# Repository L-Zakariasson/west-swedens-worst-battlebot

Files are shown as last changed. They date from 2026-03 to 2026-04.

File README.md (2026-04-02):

This is a school project for my integrated systems course.
Using C and the atmega 328p processor I am creating a very shitty battlebot.

The hardware includes a HC-06 bluetooth module, a 5 to 3,3 V logic converter, and the Motron M3T453 i2c motor controller.
It takes commands from a ps5 controller using a computer running a python script to send commands over BT serial and the bot uses  that to control two motors to provide "Tank" steering and one motor for the weapon.

The chassi is built using Lego.

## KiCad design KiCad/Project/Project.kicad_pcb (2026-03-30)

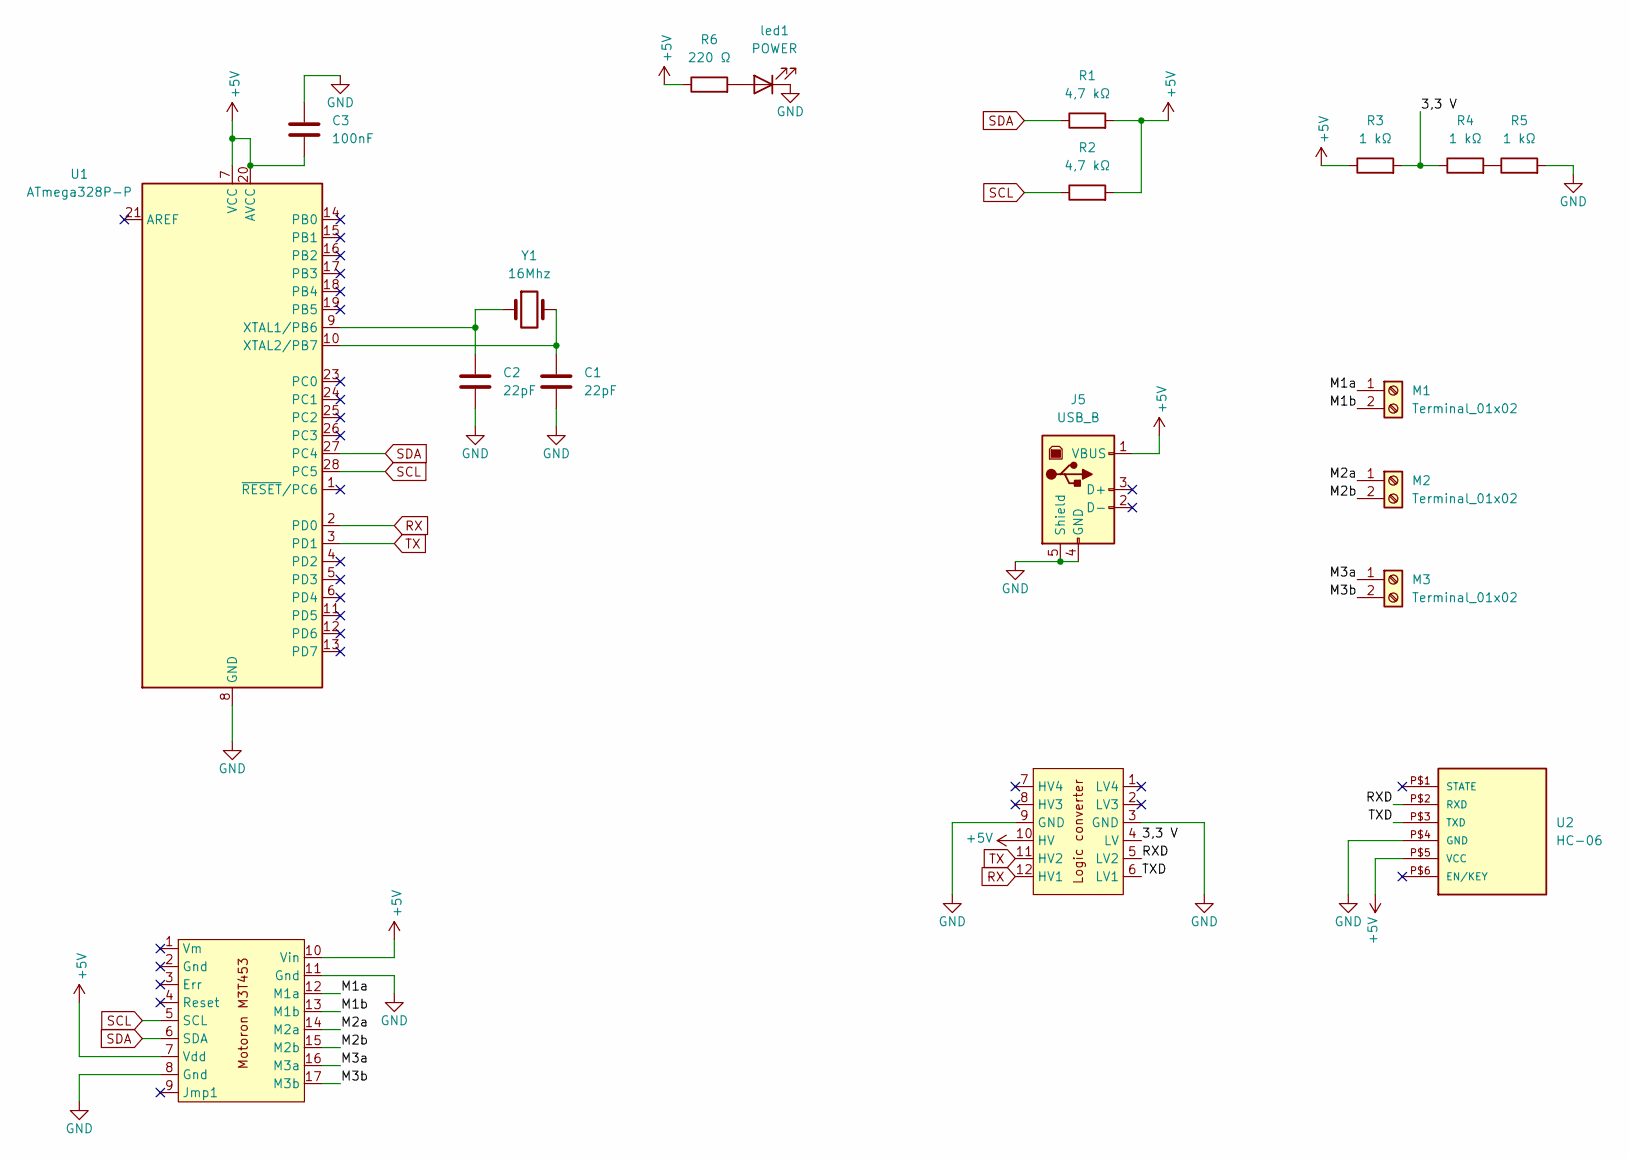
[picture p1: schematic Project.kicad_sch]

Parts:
C1, C2: 22pF; C_Disc_D5.0mm_W2.5mm_P2.50mm
C3: 100nF; C_Rect_L7.2mm_W2.5mm_P5.00mm_FKS2_FKP2_MKS2_MKP2
J5: USB_B; USB_B_Lumberg_2411_02_Horizontal
M1, M2, M3: Terminal_01x02; TerminalBlock_MetzConnect_Type094_RT03502HBLU_1x02_P5.00mm_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
R1, R2: 4,7 kΩ; R_Axial_DIN0207_L6.3mm_D2.5mm_P7.62mm_Horizontal
R3, R4, R5: 1 kΩ; R_Axial_DIN0207_L6.3mm_D2.5mm_P7.62mm_Horizontal
R6: 220 Ω; R_Axial_DIN0207_L6.3mm_D2.5mm_P7.62mm_Horizontal
U1: ATmega328P-P; ZIF 28pin den hos elektrokit, maybe
U2: HC-06
U3: motron m3t453
U5: logic converter
Y1: 16Mhz; Crystal_HC49-U_Vertical
led1: POWER; LED_D5.0mm

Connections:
+5V: C3.2, J5.1 (VBUS), R1.2, R2.2, R3.1, R6.1, U1.7 (VCC), U1.20 (AVCC), U2.P$5 (VCC), U3.7 (Vdd), U3.10 (Vin), U5.10 (HV)
/3,3 V: R3.2, R4.1, U5.4 (LV)
/M1a: M1.1, U3.12 (M1a)
/M1b: M1.2, U3.13 (M1b)
/M2a: M2.1, U3.14 (M2a)
/M2b: M2.2, U3.15 (M2b)
/M3a: M3.1, U3.16 (M3a)
/M3b: M3.2, U3.17 (M3b)
/RXD: U2.P$2 (RXD), U5.5 (LV2)
/TXD: U2.P$3 (TXD), U5.6 (LV1)
GND: C1.2, C2.2, C3.1, J5.4 (GND), J5.5 (Shield), R5.2, U1.8 (GND), U1.22 (GND), U2.P$4 (GND), U3.8 (Gnd), U3.11 (Gnd), U5.3 (GND), U5.9 (GND), led1.1 (K)
unnamed: R4.2, R5.1
unnamed: C2.1, U1.9 (XTAL1/PB6), Y1.1
unnamed: C1.1, U1.10 (XTAL2/PB7), Y1.2
unnamed: R6.2, led1.2 (A)
RX: U1.2 (PD0), U5.12 (HV1)
SCL: R2.1, U1.28 (PC5), U3.5 (SCL)
SDA: R1.1, U1.27 (PC4), U3.6 (SDA)
TX: U1.3 (PD1), U5.11 (HV2)

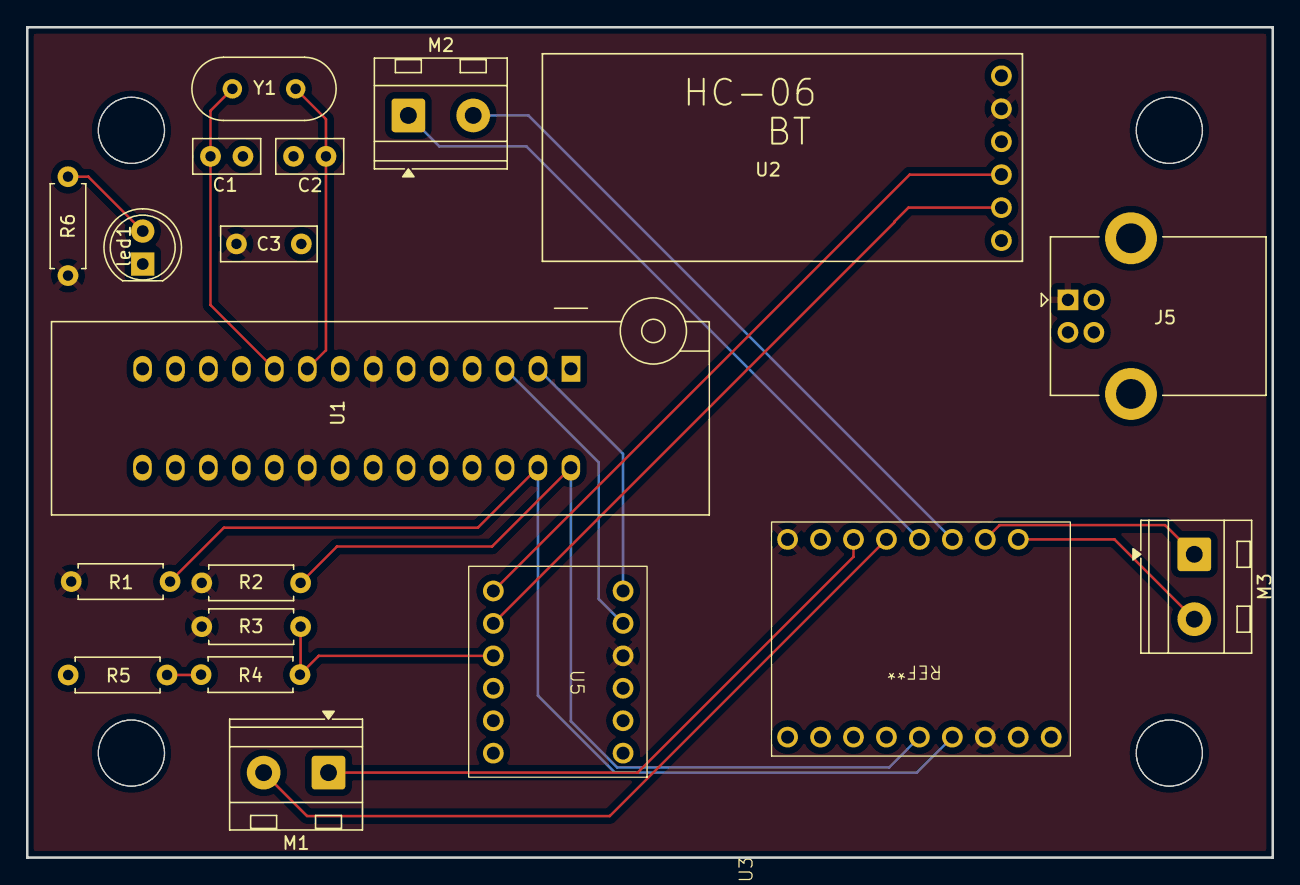
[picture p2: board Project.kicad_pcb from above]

Board: 2 copper layers, 96.0 x 64.0 mm, 19 parts (0 on the bottom side), 19 nets.

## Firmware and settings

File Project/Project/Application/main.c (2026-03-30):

/*
 * Project.c
 *
 * Created: 2026-02-10 15:39:32
 * Author : ludvig
 */ 

 
#include "include.h"


volatile uint8_t rx_input = 0;
volatile uint8_t uart_command[3] = {0,0,0};
volatile uint8_t uart_command_counter = 0;


ISR (USART_RX_vect){ /*interrupt to get serial data*/
    rx_input = UDR0;
    if (uart_command_counter < 3) {
        if (61==rx_input || 62==rx_input) {
            uart_command[0] = rx_input;
        } else if (0==(rx_input>>6) || 1==(rx_input>>6)) {
            uart_command[1] = rx_input;
        } else if (2==(rx_input>>6) || 3==(rx_input>>6)) {
            uart_command[2] = rx_input;
        }
        
        uart_command_counter++;  
    }  
}
    

int main(void)
{
     
    i2c_init(); /*setup i2c communication in atmega*/
    motron_init(); /*setup motor controller with default settings*/
    uart_init(104); /*setup uart with 9600 baud*/
    sei();
    while (1) {   
        if (uart_command_counter >= 3) {
        
            if (61 == uart_command[0]) {
                set_motor_3_speed(800);
            } else if (62 == uart_command[0]) {
                set_motor_3_speed(0);
            }
            
            if (uart_command[1]>>6 == 1) {
                uart_command[1] = uart_command[1] & 0b00111111;
                set_motor_1_speed(uart_command[1]*13);                
            } else if (uart_command[1]>>6 == 0) {
                uart_command[1] = uart_command[1] & 0b00111111;
                set_motor_1_speed(uart_command[1]*(-13));                    
            }
            
            if (uart_command[2]>>6 == 3) {
                uart_command[2] = uart_command[2] & 0b00111111;
                set_motor_2_speed(uart_command[2]*13);                 
            } else if (uart_command[2]>>6 == 2) {
                 uart_command[2] = uart_command[2] & 0b00111111;
                 set_motor_2_speed(uart_command[2]*(-13));                  
            }
                        
            uart_command_counter = 0;
        }
              
    }
}

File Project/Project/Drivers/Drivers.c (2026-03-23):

/*
 * Drivers.c
 *
 * Created: 2026-03-12 10:17:34
 *  Author: ludvig
 */ 

#include "include.h"

void i2c_init (void){
    TWCR = 0x00;
    TWBR = 0x08;            /*clock speed, under 400kHz*/
    TWCR = 0x04;
}

void i2c_start(void){
    TWCR = (1 << TWINT | (1<< TWSTA) | (1 << TWEN));
    while((TWCR & (1<<TWINT)) == 0);
}

void i2c_write (uint8_t data){
    TWDR = data;
    TWCR = (1<<TWINT) | (1<<TWEN);
    while ((TWCR & (1<<TWINT)) == 0);
}

void i2c_stop (void){
    TWCR = (1<<TWINT) | (1<<TWEN) | (1<<TWSTO);
}

void uart_init(uint8_t baud){
    UCSR0B = (1<<TXEN0) | (1<<RXEN0) | (1<<RXCIE0);
    UCSR0C = (1<<UCSZ01) | (1<<UCSZ00);
    UBRR0L = baud;
}

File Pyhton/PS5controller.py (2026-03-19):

# Example file showing a basic pygame "game loop"
import pygame
import serial

# pygame setup
pygame.init()

screen = pygame.display.set_mode((720, 360))
clock = pygame.time.Clock()
running = True

controller = pygame.joystick.Joystick(0)
serialPort = serial.Serial(
    port="COM12", baudrate=9600, bytesize=8, timeout=2, stopbits=serial.STOPBITS_ONE
)

while running:

    for event in pygame.event.get():
        if event.type == pygame.QUIT:
            running = False
	

    if controller.get_button(10) == 1:
        weapon = bytes([61])

        print(weapon)
        serialPort.write(weapon)
    else: 
        weapon = bytes([62])

        print(weapon)
        serialPort.write(weapon)

    if controller.get_axis(1) > 0:
        motorspped_l_down = bytes([abs(int(round(controller.get_axis(1)*60)))+0])
        
        print("L stick down ",motorspped_l_down)
        serialPort.write(motorspped_l_down)

    if controller.get_axis(1) < 0:
        motorspped_l_up = bytes([abs(int(round(controller.get_axis(1)*60)))+64])

        print("L stick up ",motorspped_l_up)
        serialPort.write(motorspped_l_up)       

    if controller.get_axis(3) > 0:
        motorspped_r_down = bytes([abs(int(round(controller.get_axis(3)*60)))+128])
        print("R stick down ",motorspped_r_down)
        serialPort.write(motorspped_r_down)

    if controller.get_axis(3) < 0:
        motorspped_r_up = bytes([abs(int(round(controller.get_axis(3)*60)))+192]) 
        print("R stick up ",motorspped_r_up)  
        serialPort.write(motorspped_r_up)

    pygame.display.flip() # do i need?

    clock.tick(60)  # limits FPS to 60

pygame.quit()

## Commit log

2026-03-11 v1.0
    uploading working v1 in case i fuck up the code
2026-03-12 completed KiCad
    completed KiCad with garber and drill files
2026-03-12 Update KiCad.zip
    now its done...
2026-03-12 added src,drivers and header file
    Cleaned up code and created dedicated files
2026-03-19 v1.1
    added a python script co get controller input and controll robot using two joysticks
    [Project-B_Cu.gbr, Project-B_Mask.gbr, Project-B_Paste.gbr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]
2026-03-30 v1.2
    Updated capacitor and resistor values
2026-03-30 v 1.3
    fixed pads om BT footprint
    [Project.kicad_pcb]
2026-03-30 v 1.4
    updated capacitor values, for real this time
    [Project.kicad_sch]
